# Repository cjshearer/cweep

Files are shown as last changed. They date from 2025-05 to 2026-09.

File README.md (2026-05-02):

## Overview

A compact, 34 key, solar powered, reversible, split keyboard.

<a href="https://github.com/user-attachments/assets/642829ea-e7b8-4ff3-9049-28f1e1555cb2">pcb-3d-bottom</a><a href="https://github.com/user-attachments/assets/ab504e79-e15f-4af2-8a4f-50c7394c724b">pcb-3d-top</a>

<a href="https://github.com/user-attachments/assets/e60e4d48-c13d-41c2-b896-f076ac4e2c79">pcb-B</a><a href="https://github.com/user-attachments/assets/00cfc082-f974-4577-bfa2-e2fe745e49d9">pcb-F</a>

<details>
  <summary>
    Schematic
  </summary>

  <a href="https://github.com/user-attachments/assets/647d1b9f-04d2-43af-ba33-3fea434be137">
    schematic
  </a>
</details>

## Case

The case is generated from `cweep.py` using CadQuery, with geometry extracted from user layers in `cweep.kicad_pcb`.

Generate case files to `case/`:

```sh
nix develop .#case --command python ~/repos/cweep/cweep.py
```

For interactive 3D viewing with live reloads:

```sh
nix develop .#case --command python ~/repos/cweep/cweep-dev.py
```

Changes to `cweep.py` or `cweep.kicad_pcb` automatically reload in the browser.

## Firmware

[*Generated by Shield Wizard for ZMK*](https://shield-wizard.genteure.workers.dev)

Reproducible builds with [Nix](https://nixos.org) thanks to [lilyinstarlight/zmk-nix](https://github.com/lilyinstarlight/zmk-nix):

```sh
# flash firmware with xiao dongle, resetting each board first
nix run .#flash reset reset reset dongle left right

# flash firmware with left as central, resetting each board first
nix run .#flash reset reset left_central right

# build all firmware and flash it yourself
nix build .#firmware
```

Builds in GitHub Actions coming soon.

## Bill of Materials (BOM)

| Description | Count | Value | Source |
|---|---|---|---|
| Controller | 2 | [Seeed Xiao nRF52840](https://files.seeedstudio.com/wiki/XIAO/Seeed-Studio-XIAO-Series-SOM-Datasheet.pdf) | [Octopart](https://octopart.com/102010448-seeed+studio-126049022) |
| Controller Sockets | 4 | [310-43-107-41-001000](https://datasheet.octopart.com/310-43-107-41-001000-Mill-Max-datasheet-180673429.pdf) | [Octopart](https://octopart.com/310-43-107-41-001000-mill-max-657030) |
| Controller Pins | 28 | [3320-0-00-15-00-00-03-0](https://datasheet.octopart.com/3320-0-00-15-00-00-03-0-Mill-Max-datasheet-180682269.pdf) | [Octopart](https://octopart.com/3320-0-00-15-00-00-03-0-mill-max-29613931) |
| Battery/Reset Pogo Pins | 4 | [0906-0-15-20-76-14-11-0](https://datasheet.octopart.com/0906-0-15-20-76-14-11-0-Mill-Max-datasheet-180665642.pdf) | [Octopart](https://octopart.com/0906-0-15-20-76-14-11-0-mill-max-259418) |
| Battery | 2 | [ICR10440](https://www.powerstream.com/p/ICR10440-300mAh.pdf) | [Amazon](https://www.amazon.com/dp/B08H4RC1Y5) |
| Battery Contacts | 4 | [Keystone 230-1](https://docs.rs-online.com/a10d/0900766b8106e5ee.pdf) | [Octopart](https://octopart.com/230-1-keystone-154879) |
| Power Switch | 2 | [KAN-15](https://hackaday.io/project/174738-kan-15-led-tactile-switch/log/183418-switches-switches-switches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,KAN%2D15,-Finally%2C%20I%20found) | [Amazon](https://us.amazon.com/dp/B0BHH2FBQ5) |
| Reset Button | 2 | [B3F-1020](https://omronfs.omron.com/en_US/ecb/products/pdf/en-b3f.pdf) (adafruit 367) | [Octopart](https://octopart.com/b3f-1020-omron-46944) |
| Kailh Choc V1 Keycaps | 34 | DDC Choc PBT Blanks | [Keebd](https://keebd.com/products/ddc-choc-pbt-blank-keycaps?variant=43210242785432) |
| Kailh Choc V1 Switches | 34 | [PG1350](https://cdn-shop.adafruit.com/product-files/5113/CHOC+keyswitch_Kailh-CPG135001D01_C400229.pdf) (e.g. [Sunset](https://cdn.shopify.com/s/files/1/0523/0847/6068/files/Choc_Sunset_datasheet.pdf))  | [Keebd](https://keebd.com/products/sunset-tactile-choc-switches?variant=41676091981976) |
| Kailh Choc Hotswap Sockets | 34 | [A5118](https://cdn-shop.adafruit.com/product-files/5118/5118-Choc-Socket.pdf) | [Octopart](https://octopart.com/5118-adafruit+industries-119967299) |
| Diodes | 34 | [1N4148W](https://datasheet.octopart.com/1N4148W-Diotec-datasheet-178941572.pdf) | [Octopart](https://octopart.com/1n4148w-diotec-42312312) |
| Solar Cell | 2 | [SM141K04LV](https://waf-e.dubudisk.com/anysolar.dubuplus.com/techsupport@anysolar.biz/O18Ae0B/DubuDisk/www/Gen3/SM141K04LV%20DATA%20SHEET%20202007.pdf) | [Octopart](https://octopart.com/sm141k04lv-anysolar-120091681) |
| Boost Converter | 2 | [BQ25504](https://www.ti.com/document-viewer/bq25504/datasheet) | [Octopart](https://octopart.com/bq25504rgtr-texas+instruments-20530455) |
| 4.7μF Capacitor (CHV1, CSTOR1) | 4 | [CL10A475KP8NNNC](https://datasheet.octopart.com/CL10A475KP8NNNC-Samsung-Electro-Mechanics-datasheet-11791968.pdf) | [Octopart](https://octopart.com/cl10a475kp8nnnc-samsung+electro-mechanics-9301844) |
| 10nF Capacitor (CREF1, CBYP1) | 4 | [C0603C103K5RACTU](https://octopart.com/c0603c103k5ractu-kemet-133094) | [Octopart](https://datasheet.octopart.com/C0603C103K5RACTU-Kemet-datasheet-11898999.pdf) |
| 22μH Inductor (LBST1) | 2 | [ASPI-4030S-220M-T](https://datasheet.octopart.com/ASPI-4030S-220M-T-Abracon-datasheet-27893147.pdf) | [Octopart](https://octopart.com/aspi-4030s-220m-t-abracon-29811505) |
| 4.42MΩ Resistor (ROV1) | 2 | [CRCW06034M42FKEA](https://datasheet.octopart.com/CRCW06034M42FKEA-Vishay-datasheet-175423584.pdf) | [Octopart](https://octopart.com/crcw06034m42fkea-vishay-39804278) |
| 5.49MΩ Resistor (ROV2) | 2 | [CRCW06035M49FKEA](https://datasheet.octopart.com/CRCW06035M49FKEA-Vishay-datasheet-175423584.pdf) | [Octopart](https://octopart.com/crcw06035m49fkea-vishay-39809097) |
| 3.83MΩ Resistor (RUV1, ROC2) | 4 | [CRCW06033M83FKEA](https://datasheet.octopart.com/CRCW06033M83FKEA-Vishay-datasheet-175423584.pdf) | [Octopart](https://octopart.com/crcw06033m83fkea-vishay-39857567) |
| 6.04MΩ Resistor (RUV2) | 2 | [CRCW06036M04FKEA](https://datasheet.octopart.com/CRCW06036M04FKEA-Vishay-datasheet-175423584.pdf) | [Octopart](https://octopart.com/crcw06036m04fkea-vishay-39816007) |
| 16MΩ Resistor (ROC1) | 2 | [RK73B1JTTDD166J](https://datasheet.octopart.com/RK73B1JTTDD166J-KOA-Speer-datasheet-182143539.pdf) | [Octopart](https://octopart.com/rk73b1jttdd166j-koa+speer-20075546) |
| 24AWG Stranded Silicone Wire | ~8in | N/A | [Amazon](https://www.amazon.com/dp/B01LH1G2IE) |

## Credits

This project is inspired by the work of many in the custom keyboard community:

- Pierre Chavalier's [Ferris](https://github.com/pierrechevalier83/ferris): for the original design and layout
- David Philip Barr's [Sweep](https://github.com/davidphilipbarr/Sweep/): inspiration to build a wireless, ferris-like keyboard using a daughter board for the microcontroller  
- GEIGEIGEIST's [TOTEM](https://github.com/GEIGEIGEIST/TOTEM): for it's excellent build guide, which helped me understand what types of components I may need for a wireless split keyboard
- Pete Johanson's [revxlp](https://gitlab.com/lpgalaxy/revxlp): for the usage and layout of pogo pins to connect a socketed Seeed Xiao's battery and reset pins to the PCB
- Xudongz's [Ergoblue](https://www.xudongz.com/blog/2020/ergoblue/): my initial inspiration for building a solar powered wireless keyboard
- NGuyen Vincent's [Aloidia](https://hackaday.io/project/189688-aloidia-wireless-split-solar-powered-keyboard): for the detailed build log and all-around excellent resource on building solar powered wireless keyboard

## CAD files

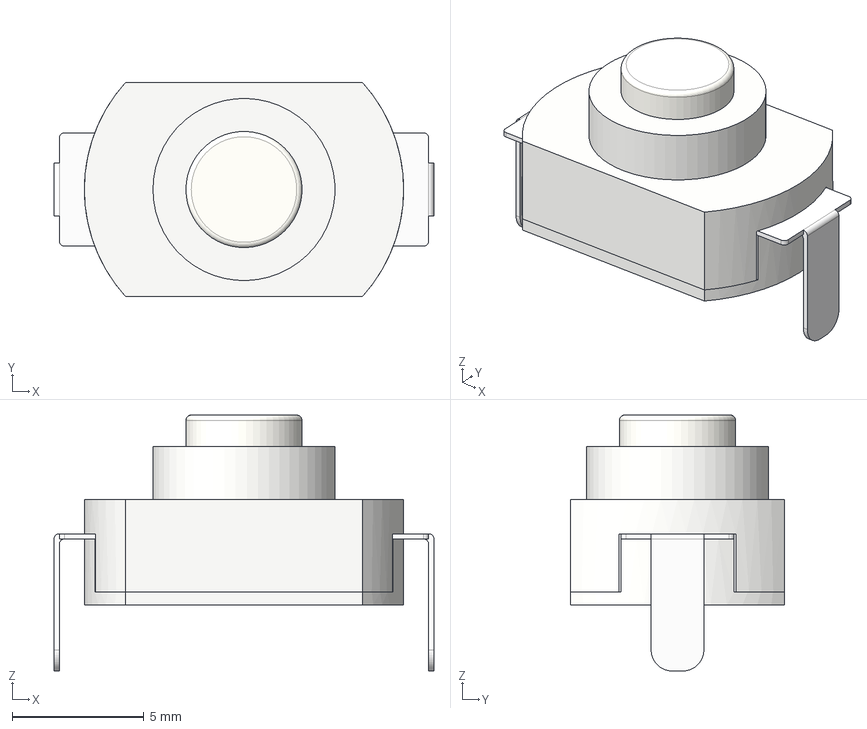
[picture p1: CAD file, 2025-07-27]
3dmodels/com_github_jgillick_KiCad-library/SW_KAN-15_PTH.step
14.4 x 8.10 x 9.70 mm

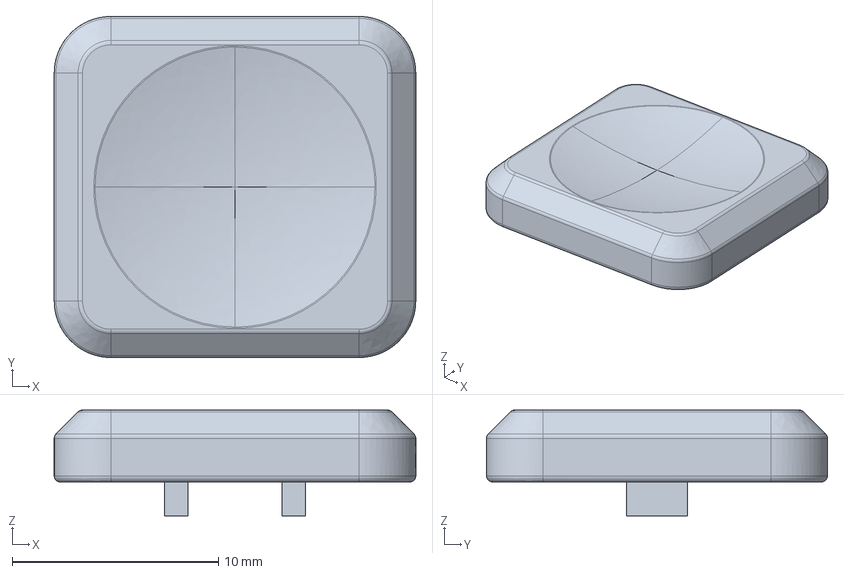
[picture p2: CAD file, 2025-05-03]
3dmodels/com_github_klouderone_KEA-choc-keycaps/KEA Choc V1 Choc Spaced Keycap 1u.stp
17.6 x 16.6 x 5.14 mm

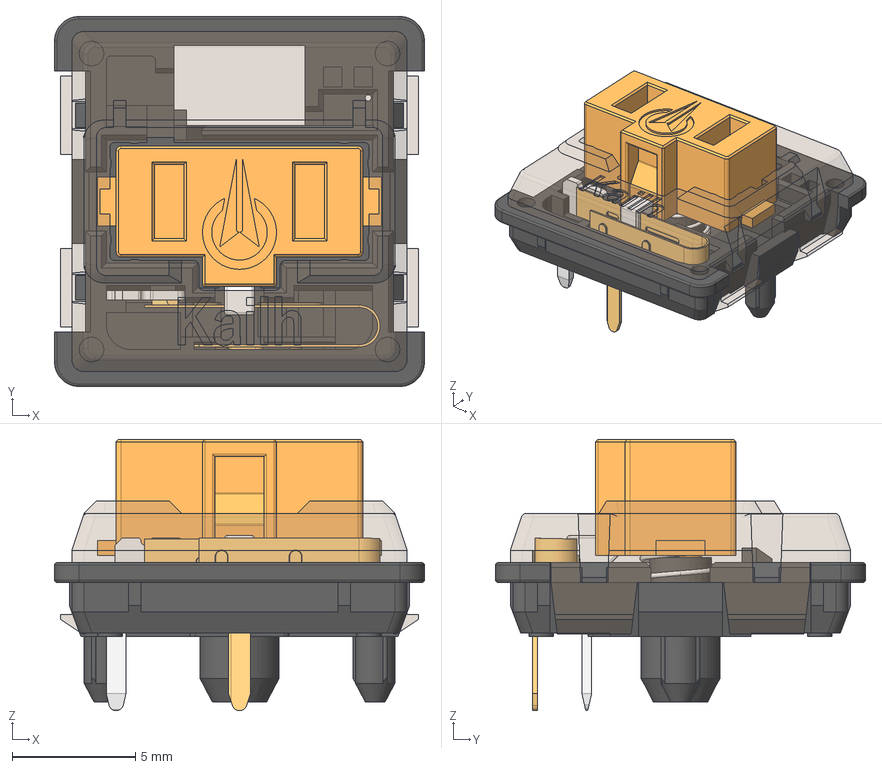
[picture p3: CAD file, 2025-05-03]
3dmodels/com_github_koktoh_keyswitch_model/sunset_tactile.step
15.0 x 15.0 x 11.0 mm
shrunken_spring
top
pin1
bottom
contact
stem_sunset_tactile
pin2

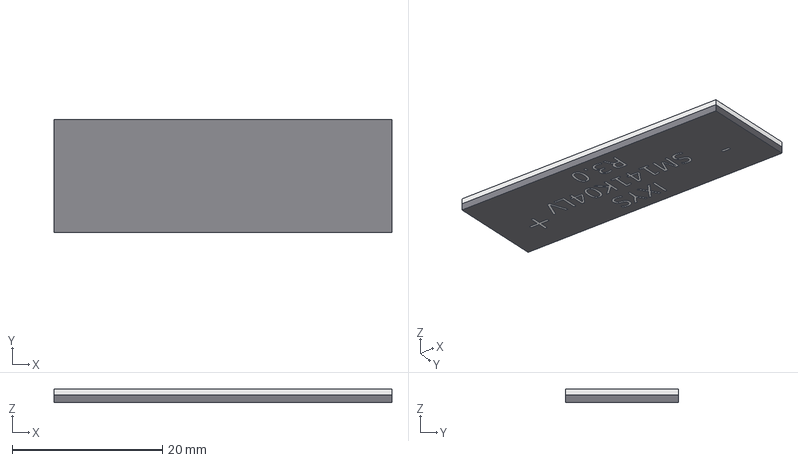
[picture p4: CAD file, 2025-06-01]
3dmodels/com_github_PeakSat_COMMSBoard_PCB/SM141K04LV.step
45.0 x 15.0 x 1.81 mm
+
SM141K04LV_substrate
SM141K04LV
SM141K04LV001
IXYS
R3.0

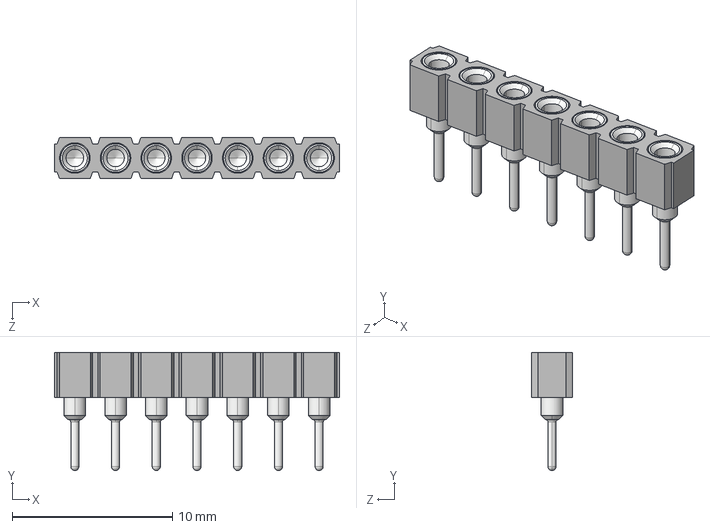
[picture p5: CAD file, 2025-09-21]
3dmodels/com_mouser_Mill-Max_310-43-107-41-001000/310-43-107-41-001000.stp
17.8 x 7.37 x 2.54 mm
P3XX-11-010-00-000000_P307-11-010-00-000000

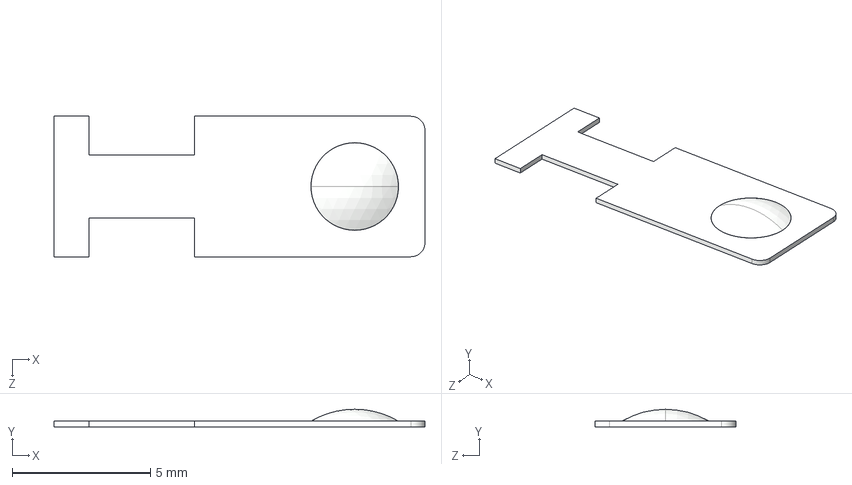
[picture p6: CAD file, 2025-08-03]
3dmodels/com_snapeda_Keystone/230-1.step
13.4 x 0.635 x 5.08 mm

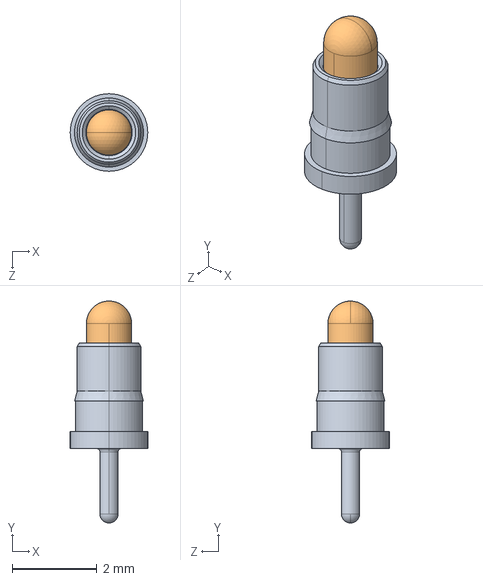
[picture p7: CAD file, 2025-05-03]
3dmodels/com_snapeda_Mill-Max_0906-0-15-20-76-14-11-0/0906-0-15-20-76-14-11-0.STEP
1.83 x 5.23 x 1.83 mm

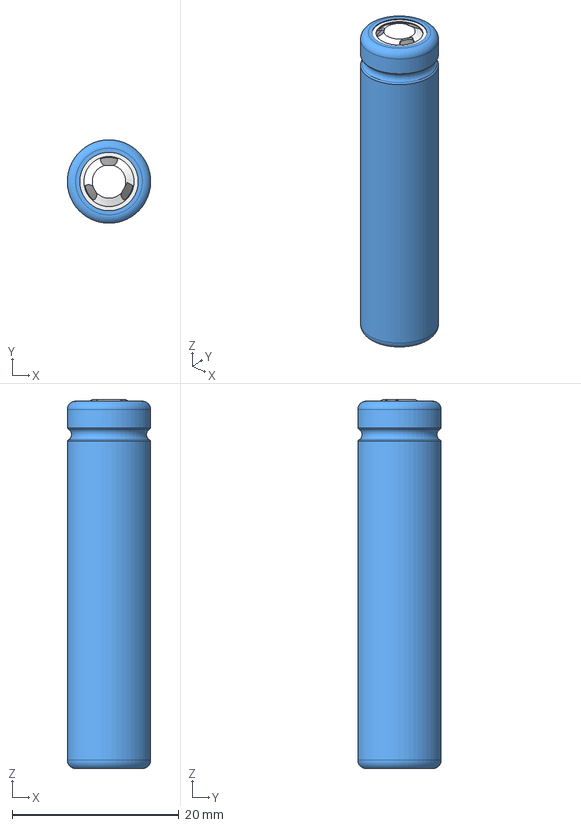
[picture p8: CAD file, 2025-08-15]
3dmodels/com_grabcad_ni_ni/10440.stp
10.00 x 9.99 x 44.2 mm

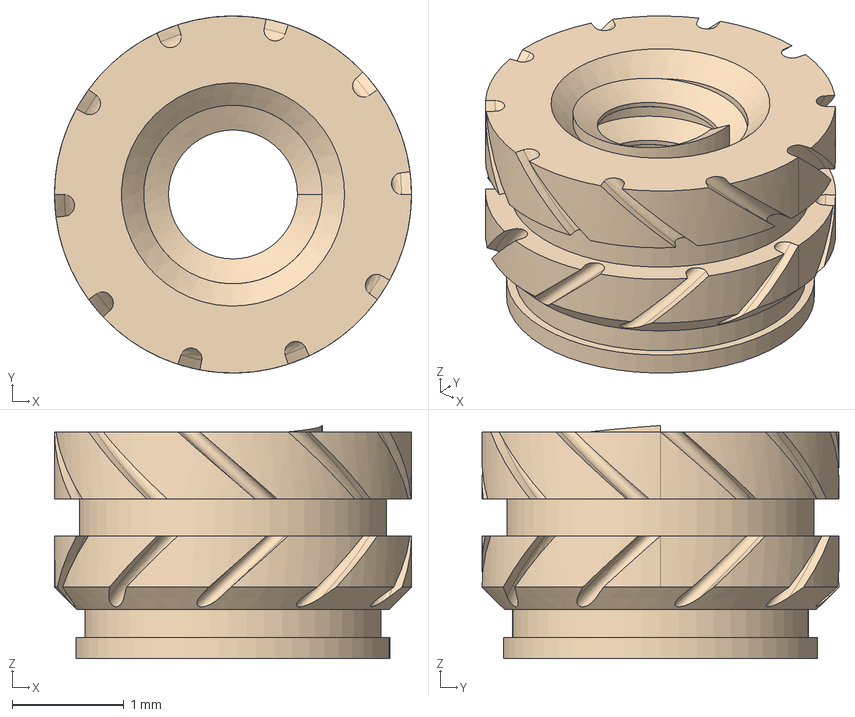
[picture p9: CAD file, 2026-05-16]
3dmodels/com_grabcad_shrey.g-2/m2x2x3.2_threaded-insert.step
3.20 x 3.20 x 2.09 mm

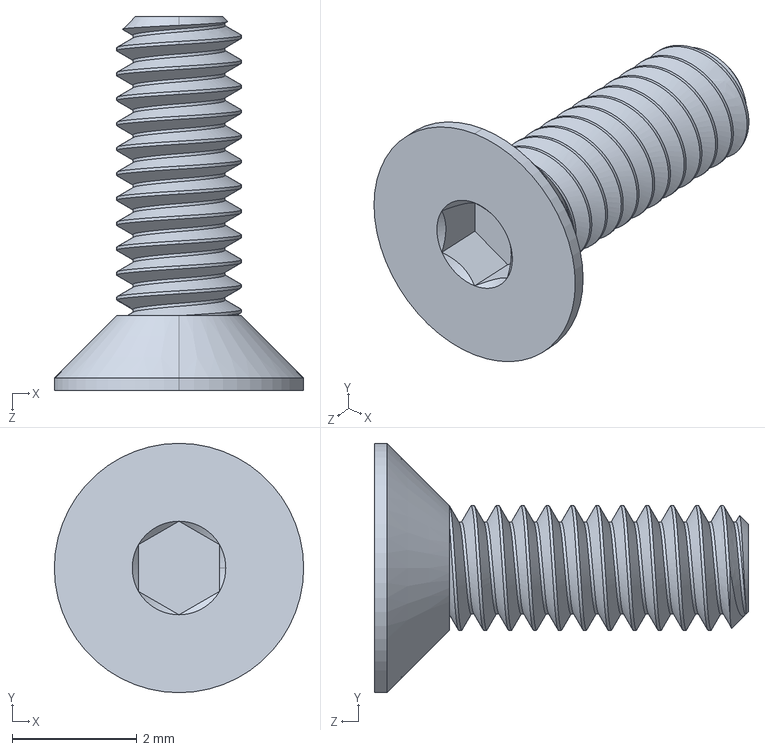
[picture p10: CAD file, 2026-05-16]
3dmodels/com_mcmaster/91294A004_hex_drive_flat_head_screw_m2x0.4x6.stp
4.00 x 4.00 x 6.00 mm

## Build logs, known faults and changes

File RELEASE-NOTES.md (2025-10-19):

## [0.2.1](https://github.com/cjshearer/cweep/compare/750787b...b826d47) (2025-10-19)

Features:

- feat: add firmware ([113380c](https://github.com/cjshearer/cweep/commit/113380c49dd21aa6a25552184e1d4649aa102922))
- feat: add direnv ([0741a76](https://github.com/cjshearer/cweep/commit/0741a76e008e20e344ac9841a19f397b33f8722a))
- feat: add cweep keymap ([b633da6](https://github.com/cjshearer/cweep/commit/b633da6e0e82b8d76da349570988fb77a3e8a74f))

Fixes:

- fix: add missing battery contacts ([88c9a56](https://github.com/cjshearer/cweep/commit/88c9a562178b62f404370517add00983ee9f83f7))
- fix: halves connect to dongle ([83709e9](https://github.com/cjshearer/cweep/commit/83709e9c3aa1ab0f535ac7c3a69aa6747a3f2635))
- fix: flip ground solder jumper pad ([0215cbb](https://github.com/cjshearer/cweep/commit/0215cbbeff3e0590acb6301ef7a46215b0a98009))
- fix: don't overlap jumper pad and rst courtyards ([0fad872](https://github.com/cjshearer/cweep/commit/0fad872a907a0e8da5768718c7a9fdc3f7a297eb))

Refactors:

- refactor: use low-leakage diodes ([2f691b7](https://github.com/cjshearer/cweep/commit/2f691b733773dad2b2d1976309e2343cbaab739a))
- refactor: dedup part for RUV1 and ROC2 ([7067be4](https://github.com/cjshearer/cweep/commit/7067be46746762ad8baf1e19320a376f6aba2be4))

Documentation:

- docs: update images ([5de7789](https://github.com/cjshearer/cweep/commit/5de77895a8b004a01328f5c3008dabf0e4f57216))
- docs: fix wrong image src ([6230c71](https://github.com/cjshearer/cweep/commit/6230c71ce97863de70a56a3e878f5c5da012389e))
- docs: shorten link for 24AWG wire ([95858cf](https://github.com/cjshearer/cweep/commit/95858cf211d6f48bfaf01f0d3ccf909587eeb3d1))

## [0.2.0](https://github.com/cjshearer/cweep/compare/6999a66...750787b) (2025-09-21)

Documentation:

- docs: update images ([49f538c](https://github.com/cjshearer/cweep/commit/49f538cf55e573baeba76378d8cd62a7de93a850))

Refactors:

- refactor: replace 311-13-107-41-001000 socket with cheaper alternative (310-43-107-41-001000) ([27b2981](https://github.com/cjshearer/cweep/commit/27b29816245fa6ae4417d3368c466a664c287341))

## [0.1.0](https://github.com/cjshearer/cweep/compare/d12c479...6999a66) (2025-09-21)

Fixes:

- fix: replace 310-87-107-41-001101 socket with normally stocked 311-13-107-41-001000 ([e322841](https://github.com/cjshearer/cweep/commit/e3228419793ac6dbd01cdbf91dbdef63a59cec45))

Documentation:

- docs: update KAN-15 with active source ([4c134dd](https://github.com/cjshearer/cweep/commit/4c134dd85159a258c3dca58db751e88ffd1d7f4d))

## [0.0.0](https://github.com/cjshearer/cweep/commit/d12c479) (2025-09-20)

init

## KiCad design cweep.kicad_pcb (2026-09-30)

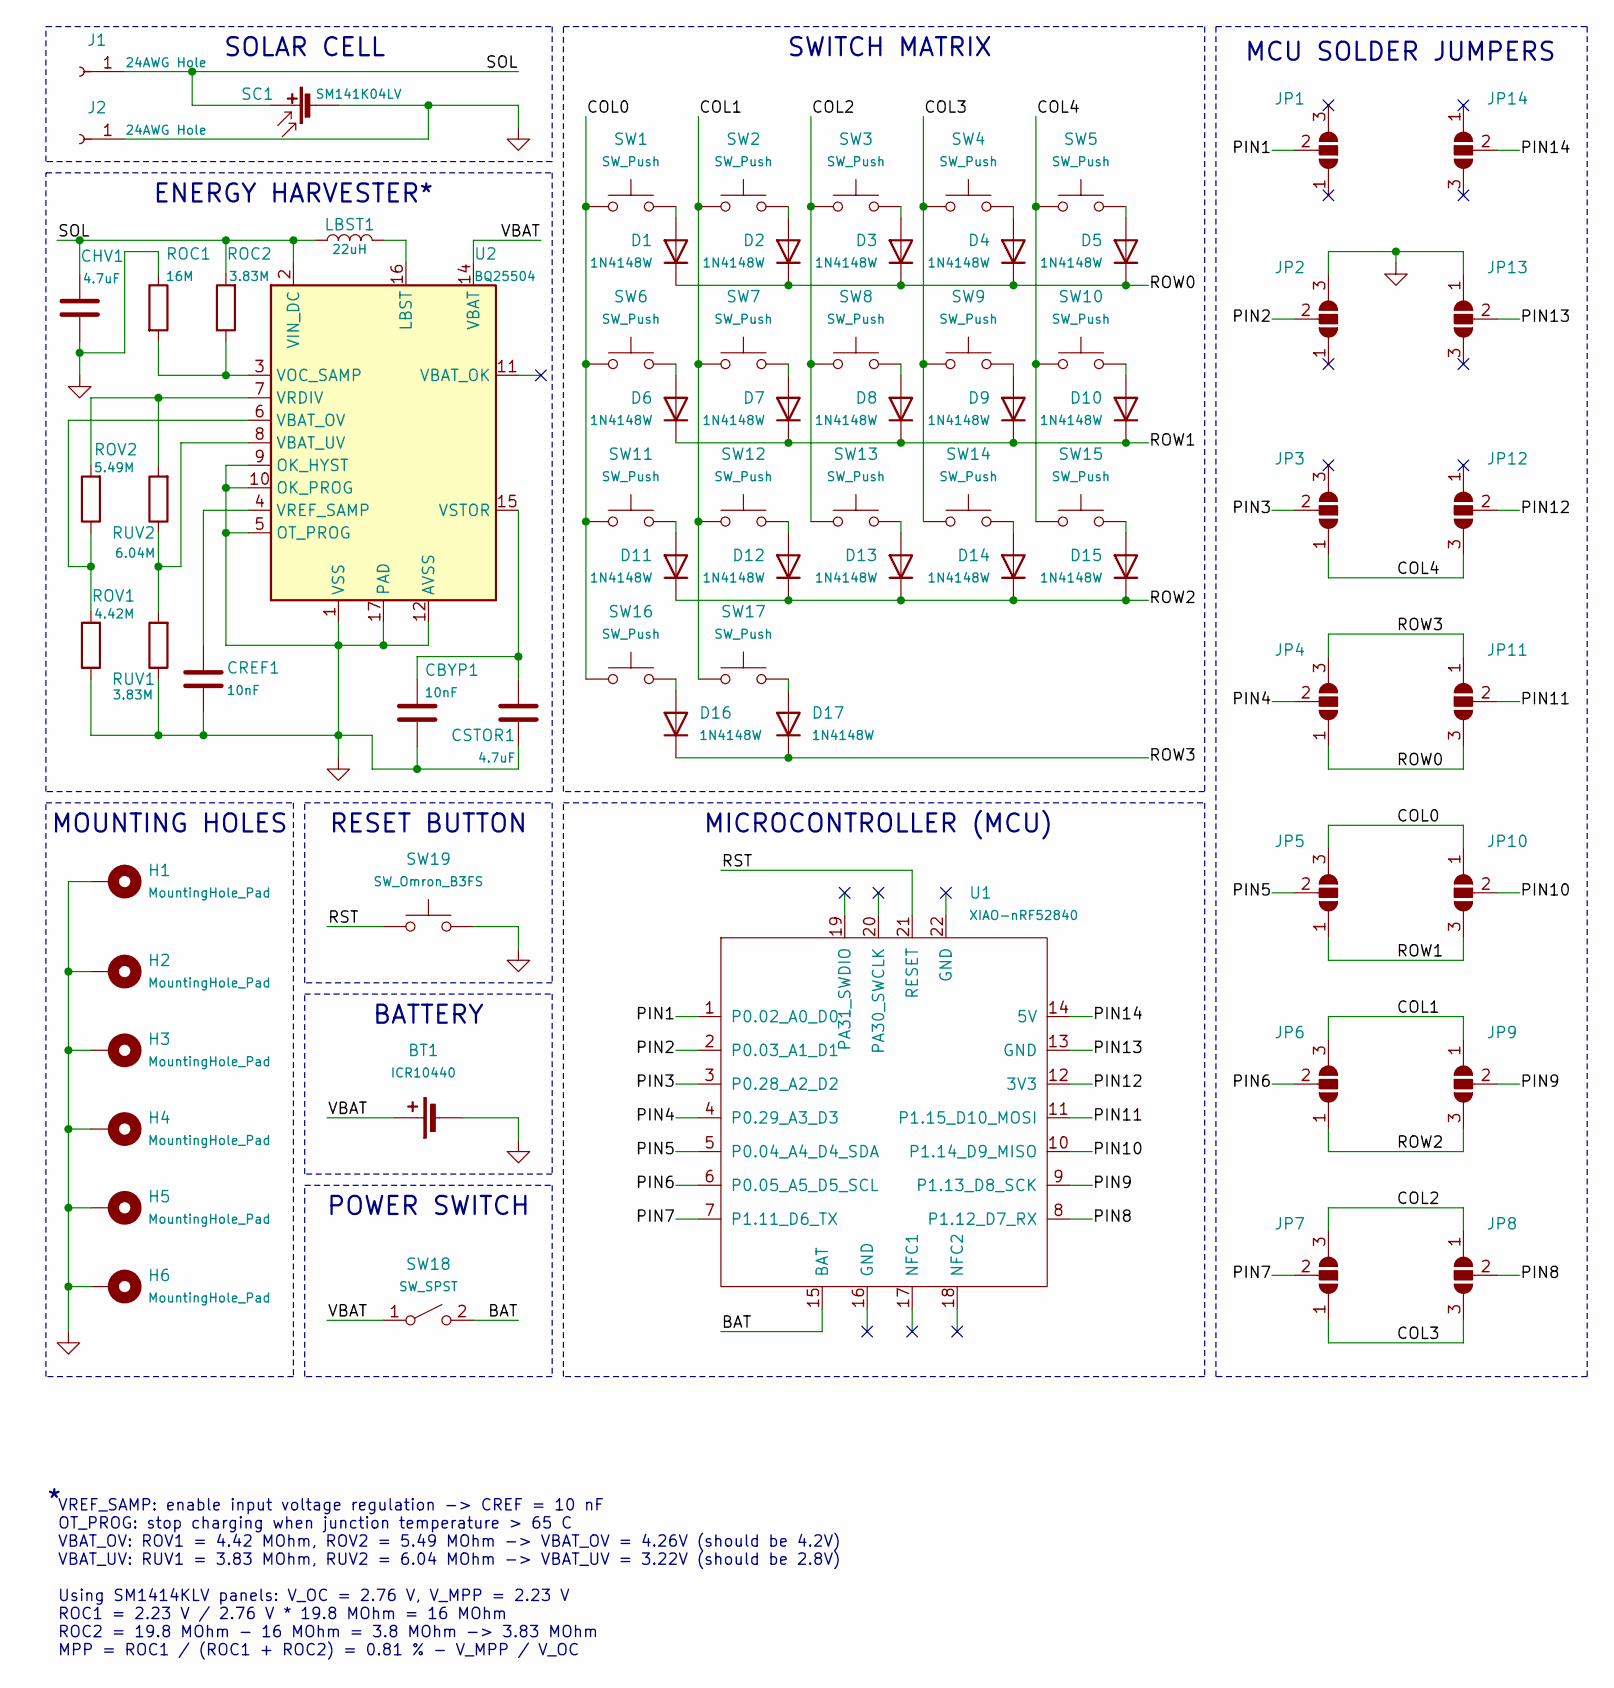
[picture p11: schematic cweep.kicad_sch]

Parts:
BT1: ICR10440; BatteryHolder_Keystone_230-1_1x10440
CBYP1: 10nF; C_0603_1608Metric_Pad1.08x0.95mm_HandSolder
CHV1: 4.7uF; C_0603_1608Metric_Pad1.08x0.95mm_HandSolder
CREF1: 10nF; C_0603_1608Metric_Pad1.08x0.95mm_HandSolder
CSTOR1: 4.7uF; C_0603_1608Metric_Pad1.08x0.95mm_HandSolder
D1, D2, D3, D4, D5, D6, D7, D8, D9, D10, D11, D12, D13, D14, D15, D16, D17: 1N4148W; D_SOD-123_Reversible
H1, H2, H3, H4, H5, H6: MountingHole_Pad; MountingHole_2.2mm_M2_DIN965_Pad
J1, J2: 24AWG Hole; SolderWire-0.127sqmm_1x01_D0.48mm_OD1mm_Relief
JP1, JP2, JP3, JP4, JP5, JP6, JP7, JP8, JP9, JP10, JP11, JP12, JP13, JP14: SolderJumper_3_Open; SolderJumper-3_P2.0mm_Open_TrianglePad1.0x1.5mm_Reversible
LBST1: 22uH; L_Abracon_ASPI-4030S_Reversible
ROC1: 16M; R_0603_1608Metric_Pad0.98x0.95mm_HandSolder
ROC2: 3.83M; R_0603_1608Metric_Pad0.98x0.95mm_HandSolder
ROV1: 4.42M; R_0603_1608Metric_Pad0.98x0.95mm_HandSolder
ROV2: 5.49M; R_0603_1608Metric_Pad0.98x0.95mm_HandSolder
RUV1: 3.83M; R_0603_1608Metric_Pad0.98x0.95mm_HandSolder
RUV2: 6.04M; R_0603_1608Metric_Pad0.98x0.95mm_HandSolder
SC1: SM141K04LV
SW1, SW2, SW3, SW4, SW5, SW6, SW7, SW8, SW9, SW10, SW11, SW12, SW13, SW14, SW15, SW16, SW17: SW_Push; SW_Hotswap_Kailh_Choc_V1_1.00u_Reversible
SW18: SW_SPST; SW_KAN-15_PHT_Reversible
SW19: SW_Omron_B3FS; SW_TH_Tactile_Omron_B3F-102x_Reversible
U1: XIAO-nRF52840; XIAO-nRF52840_Reversible
U2: BQ25504; VQFN-16-1EP_3x3mm_P0.5mm_EP1.68x1.68mm

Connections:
/BAT: SW18.2 (B), U1.15 (BAT)
/COL0: JP5.3 (B), JP10.1 (A), SW1.1, SW6.1, SW11.1, SW16.1
/COL1: JP6.3 (B), JP9.1 (A), SW2.1, SW7.1, SW12.1, SW17.1
/COL2: JP7.3 (B), JP8.1 (A), SW3.1, SW8.1, SW13.1
/COL3: JP7.1 (A), JP8.3 (B), SW4.1, SW9.1, SW14.1
/COL4: JP3.1 (A), JP12.3 (B), SW5.1, SW10.1, SW15.1
/PIN1: JP1.2 (C), U1.1 (P0.02_A0_D0)
/PIN2: JP2.2 (C), U1.2 (P0.03_A1_D1)
/PIN3: JP3.2 (C), U1.3 (P0.28_A2_D2)
/PIN4: JP4.2 (C), U1.4 (P0.29_A3_D3)
/PIN5: JP5.2 (C), U1.5 (P0.04_A4_D4_SDA)
/PIN6: JP6.2 (C), U1.6 (P0.05_A5_D5_SCL)
/PIN7: JP7.2 (C), U1.7 (P1.11_D6_TX)
/PIN8: JP8.2 (C), U1.8 (P1.12_D7_RX)
/PIN9: JP9.2 (C), U1.9 (P1.13_D8_SCK)
/PIN10: JP10.2 (C), U1.10 (P1.14_D9_MISO)
/PIN11: JP11.2 (C), U1.11 (P1.15_D10_MOSI)
/PIN12: JP12.2 (C), U1.12 (3V3)
/PIN13: JP13.2 (C), U1.13 (GND)
/PIN14: JP14.2 (C), U1.14 (5V)
/ROW0: D1.1 (K), D2.1 (K), D3.1 (K), D4.1 (K), D5.1 (K), JP4.1 (A), JP11.3 (B)
/ROW1: D6.1 (K), D7.1 (K), D8.1 (K), D9.1 (K), D10.1 (K), JP5.1 (A), JP10.3 (B)
/ROW2: D11.1 (K), D12.1 (K), D13.1 (K), D14.1 (K), D15.1 (K), JP6.1 (A), JP9.3 (B)
/ROW3: D16.1 (K), D17.1 (K), JP4.3 (B), JP11.1 (A)
/RST: SW19.1, U1.21 (RESET)
/SOL: CHV1.1, J1.1, LBST1.1, ROC2.2, SC1.1 (+), U2.2 (VIN_DC)
/VBAT: BT1.1 (+), SW18.1 (A), U2.14 (VBAT)
GND: BT1.2 (-), CBYP1.2, CHV1.2, CREF1.2, CSTOR1.2, H1.1, H2.1, H3.1, H4.1, H5.1, H6.1, J2.1, JP2.3 (B), JP13.1 (A), ROC1.1, ROV1.1, RUV1.1, SC1.2 (-), SW19.2, U2.1 (VSS), U2.5 (OT_PROG), U2.9 (OK_HYST), U2.10 (OK_PROG), U2.12 (AVSS), U2.13 (VSS), U2.17 (PAD)
unnamed: D1.2 (A), SW1.2
unnamed: D2.2 (A), SW2.2
unnamed: D3.2 (A), SW3.2
unnamed: D4.2 (A), SW4.2
unnamed: D5.2 (A), SW5.2
unnamed: D6.2 (A), SW6.2
unnamed: D7.2 (A), SW7.2
unnamed: D8.2 (A), SW8.2
unnamed: D9.2 (A), SW9.2
unnamed: D10.2 (A), SW10.2
unnamed: D11.2 (A), SW11.2
unnamed: D12.2 (A), SW12.2
unnamed: D13.2 (A), SW13.2
unnamed: D14.2 (A), SW14.2
unnamed: D15.2 (A), SW15.2
unnamed: D16.2 (A), SW16.2
unnamed: D17.2 (A), SW17.2
unnamed: LBST1.2, U2.16 (LBST)
unnamed: ROV1.2, ROV2.1, U2.6 (VBAT_OV)
unnamed: RUV1.2, RUV2.1, U2.8 (VBAT_UV)
unnamed: ROC1.2, ROC2.1, U2.3 (VOC_SAMP)
unnamed: ROV2.2, RUV2.2, U2.7 (VRDIV)
unnamed: CREF1.1, U2.4 (VREF_SAMP)
unnamed: CBYP1.1, CSTOR1.1, U2.15 (VSTOR)

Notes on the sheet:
MCU SOLDER JUMPERS
VREF_SAMP: enable input voltage regulation -> CREF = 10 nF OT_PROG: stop charging when junction temperature > 65 C VBAT_OV: ROV1 = 4.42 MOhm, ROV2 = 5.49 MOhm -> VBAT_OV = 4.26V (should be 4.2V) VBAT_UV: RUV1 = 3.83 MOhm, RUV2 = 6.04 MOhm -> VBAT_UV = 3.22V (should be 2.8V) Using SM1414KLV panels: 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
BATTERY
ENERGY HARVESTER*
SWITCH MATRIX
RESET BUTTON
MICROCONTROLLER (MCU)
POWER SWITCH
SOLAR CELL
MOUNTING HOLES

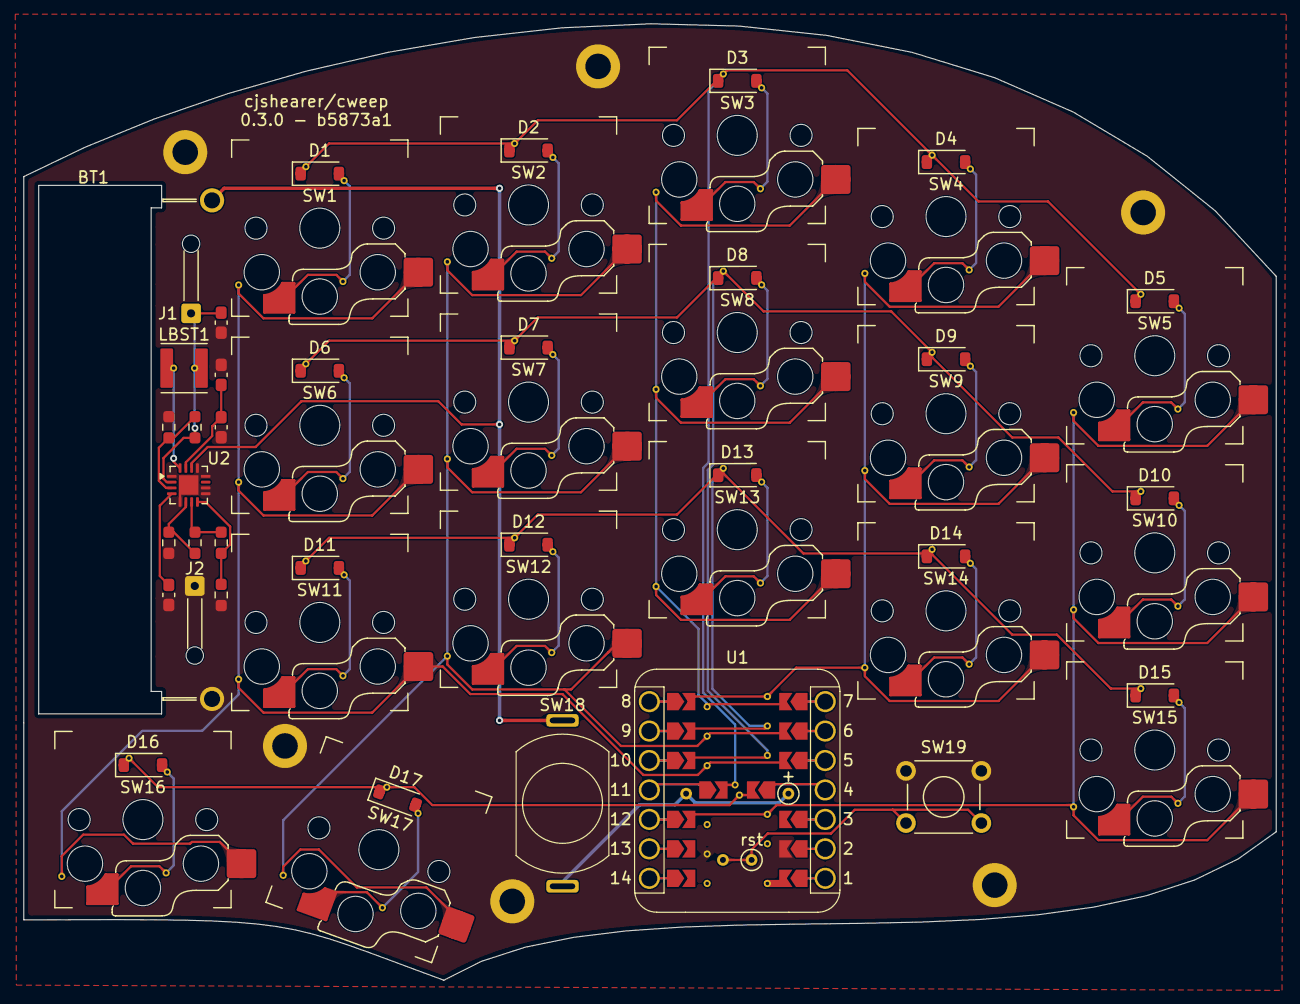
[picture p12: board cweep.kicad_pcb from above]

Board: 2 copper layers, 108.0 x 82.5 mm, 73 parts (1 on the bottom side), 52 nets.

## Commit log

2025-05-03 feat: add basic layout
    [cweep.kicad_pcb, cweep.kicad_sch]
2025-05-03 feat: add initial board layout
    [cweep.kicad_pcb]
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2025-05-03 feat: add matrix wiring
    [cweep.kicad_pcb, cweep.kicad_sch]
2025-05-03 refactor: flatten directory structure
    [KEA Choc V1 Choc Spaced Keycap 1u.stp, cweep.kicad_pcb, pcb_connector_310-87-107-41-001101.stp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]
2025-05-03 feat: add MCU battery pogo pin
    [0906-0-15-20-76-14-11-0.STEP, cweep.kicad_pcb, cweep.kicad_sch]
2025-05-03 feat: add MCU reset pogo pin
    [cweep.kicad_pcb]
2025-05-03 fix: mark unused pins
    [cweep.kicad_pcb, cweep.kicad_sch]
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2025-05-05 feat: add matrix-to-mcu routes
    [cweep.kicad_pcb, cweep.kicad_sch]
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2025-05-20 feat: add solar charging circuit
    [25mm-37mm-5mm-lipo-battery.step, RGT0016C.stp, cweep.kicad_pcb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]
2025-05-20 feat: add solar footprint and models
    [SM141K04LV.step, cweep.kicad_pcb, cweep.kicad_sch]
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2025-05-26 refactor: add R/L suffix
    [battery-13853-sparkfun-25x15x4.step, cweep.kicad_pcb, cweep.kicad_sch]
2025-05-26 feat: add matrix traces
    [cweep.kicad_pcb, cweep.kicad_sch]
2025-05-26 fix: placement for key-cap tolerances
    [cweep.kicad_pcb, cweep.kicad_sch]
2025-05-27 refactor: shorten column 0 trace
    [cweep.kicad_pcb, cweep.kicad_sch]
2025-05-28 docs: update bill-of-materials and todos
    [cweep.kicad_sch]
2025-05-31 refactor: remove unused no-connect
    [cweep.kicad_sch]
2025-05-31 fix: battery height
    [cweep.kicad_pcb]
2025-05-31 feat: add battery cutout
    [cweep.kicad_pcb]
2025-05-31 feat: add battery jst header
    [cweep.kicad_pcb, cweep.kicad_sch]
2025-05-31 fix: close hole in battery model
    [battery-13853-sparkfun-25x15x4.step]
2025-06-01 feat: add edge cuts
    [cweep.kicad_pcb]
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2025-06-01 refactor: fix solar cell appearance
    [SM141K04LV.step, cweep.kicad_pcb]
2025-06-07 feat: add mounting hole pads
    [cweep.kicad_pcb, cweep.kicad_sch]
2025-06-07 refactor: add plot settings
    [cweep.kicad_pcb]
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2025-06-21 feat: add solar harvester components
    [cweep.kicad_pcb, cweep.kicad_sch]
2025-06-21 fix: avoid text clipping
    [cweep.kicad_pcb]
2025-06-21 fix: add missing switch track
    [cweep.kicad_pcb]
2025-06-21 feat: add tracks for solar harvester
    [cweep.kicad_pcb]
2025-06-22 refactor: shorten row trace
    [cweep.kicad_pcb]
2025-07-26 refactor: typo in ultralibrarian
    [RGT0016C.stp, cweep.kicad_pcb, cweep.kicad_sch]
2025-07-27 feat: add reset button and power switch
    [SW_KAN-15_PTH.step, cweep.kicad_pcb, cweep.kicad_sch]
2025-08-01 fix: reorganize parts for better fit
    [cweep.kicad_pcb]
2025-08-02 fix: connect solar components to top pogo pin
    [cweep.kicad_pcb, cweep.kicad_sch]
2025-08-03 feat: battery capacity 110mAh -> 350mAh
    [230-1.step, AAA-Battery.STEP, battery-13853-sparkfun-25x15x4.step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]
2025-08-05 fix: remove unused pogo pins from solar cell
    [cweep.kicad_pcb]
2025-08-05 fix: battery connector spacing
    [cweep.kicad_pcb]
2025-08-06 fix: re-attach solar components
    [cweep.kicad_pcb]
2025-08-06 refactor: clean up solar fabrication labels
    [cweep.kicad_pcb]
2025-08-07 fix: align reset switch with power switch
    [cweep.kicad_pcb]
2025-08-08 fix: re-attach traces for gpio, power, and reset switches
    [cweep.kicad_pcb, cweep.kicad_sch]
2025-08-09 refactor: improve traces routing
    [cweep.kicad_pcb]
2025-08-09 fix: minor footprint and label alignments
    [cweep.kicad_pcb, cweep.kicad_sch]
2025-08-09 feat: add case mounting holes
    [cweep.kicad_pcb, cweep.kicad_sch]
2025-08-09 feat: 2.5mm -> 2.2mm mounting holes
    [cweep.kicad_pcb, cweep.kicad_sch]
2025-08-09 fix: visually align power and reset switches
    [cweep.kicad_pcb]
2025-08-09 fix: join solar ground zone and avoid silkscreen clipping
    [cweep.kicad_pcb, cweep.kicad_sch]
2025-08-10 fix: add missing B3F-102x model
    The model is broken and will be until
    https://gitlab.com/kicad/libraries/kicad-packages3D/-/merge_requests/1239
    lands.
    [cweep.kicad_pcb]
2025-08-10 refactor: add solar cell contact labels
    [cweep.kicad_pcb]
2025-08-10 refactor: center battery silkscreen label
    [cweep.kicad_pcb]
2025-08-10 fix: solar cell contact radius
    [cweep.kicad_pcb]
2025-08-10 refactor: reorganize battery schematic
    [cweep.kicad_sch]
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2025-08-15 fix: AAA -> 10440
    [10440.stp, AAA-Battery.STEP, cweep.kicad_pcb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]
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2025-09-09 feat: make keyboard switch reversible
    * fix: use SMD diode to accommodate reversible switch
    [cweep.kicad_pcb, cweep.kicad_sch]
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2025-09-09 fix: move capacitors nearer BQ25504
    The layout guidelines for the BQ25504 recommend
    placing the output capacitors as close as possible
    to the IC, followed by the input capacitors, and
    finally the inductor.
    Previously, I had this backwards, but with this
    commit the components are now in the recommended
    order.
    [cweep.kicad_pcb]
2025-09-09 fix: solar cell placement
    [cweep.kicad_pcb]
2025-09-09 fix: increase battery cutout
    I increased the size of the battery cutout to
    ensure the battery clips fit in the cutout. I left
    the battery clips where they were, since they are
    42.99mm apart, which is 1mm less than what the
    datasheet recommends for a AAA battery. However,
    the 10440 battery I will be using is 1mm smaller
    than a AAA, so this should be fine.
    [cweep.kicad_pcb]
2025-09-09 fix: xiao silkscreen
    The silkscreen for the reversible xiao footprint
    was confusing, so I updated it to be more clear.
    [cweep.kicad_pcb]
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2025-09-17 fix: correct footprint for inductor
    [cweep.kicad_pcb, cweep.kicad_sch]
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2025-09-19 fix: remove unused zone exclusion
    [cweep.kicad_pcb]
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2025-09-21 fix: replace socket with on normally in stock
    [311-13-107-41-001000.STEP, cweep.kicad_pcb, pcb_connector_310-87-107-41-001101.stp]
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2025-09-21 refactor: replace socket with cheaper alternative
    [310-43-107-41-001000.stp, 311-13-107-41-001000.STEP, cweep.kicad_pcb]
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2025-09-21 refactor: use low-leakage diodes
2025-09-25 fix: add missing battery contacts
2025-10-16 fix: flip ground solder jumper pad
    The MCU's GND solder jumper pad was incorrectly
    flipped in the PCB layout, requiring it to be
    bridged on the wrong side.
    This commit corrects the orientation of the solder
    jumper, so that it can be bridged on the correct
    side. Now, solder jumpers should all be bridged on
    the back of the PCB, regardless of which side of
    the keyboard the PCB is used for.
    [cweep.kicad_pcb]
2025-10-19 fix: don't overlap jumper pad and rst courtyards
    [cweep.kicad_pcb]
2025-10-19 docs: shorten link for 24AWG wire
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2025-10-19 feat: annotate hotswap kailh choc for case generation
    To generate the case for each side of the
    keyboard, I will be annotating the footprint and
    placement of each physical component with F.Right,
    B.Right, F.Left, or B.Left (User.1 through
    User.4).
    In this commit, I have annotated the hotswap kailh
    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
    [cweep.kicad_pcb]
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2025-10-20 fix: close gap in power switch F.Left annotation
    [cweep.kicad_pcb]
2025-10-22 fix: use accurate kailh choc CPG135001S30 socket
    There were no high quality footprints for the
    Kailh Choc hotswap sockets, so I created one based
    on the original line art from the datasheet to
    improve accuracy.
    [cweep.kicad_pcb]
2025-10-22 fix: power switch overlapping courtyard
    [cweep.kicad_pcb]
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2025-11-23 feat: add reset switch cutouts and model paths
    [cweep.kicad_pcb]
2025-11-23 refactor: swap wrl for stp
    STEP exports better for use in OpenScad.
    [cweep.kicad_pcb]
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2025-11-23 fix: remove small walls from switch cutouts
    [cweep.kicad_pcb]
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2025-11-27 fix: correct user layer assignments for front and back
    [cweep.kicad_pcb]
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2025-11-27 refactor: join right and left annotations
    Consolidate left/right cutout annotations into
    unified front/back layers. Prepare for future use
    of freed layers for fill regions.
    [cweep.kicad_pcb]
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2025-12-28 fix: cutout kailh hotswap contact
    [cweep.kicad_pcb]
2025-12-30 fix: close excess battery cutout for bottom plate
    [cweep.kicad_pcb]
2025-12-30 fix: kailh footprint is properly reversed
    [cweep.kicad_pcb]
2025-12-30 feat: add threaded M2 DIN 965 cutout to bottom plate
    [cweep.kicad_pcb]
2026-01-03 refactor: build plates from just bottom and top plate
    [cweep.kicad_pcb, cweep.scad]
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2026-02-17 refactor: replace some polygons with rectangles
    [cweep.kicad_pcb]
2026-02-22 fix: close cutout for omron switch
    [cweep.kicad_pcb]
2026-02-25 fix: close cutout for kailh choc sockets
    [cweep.kicad_pcb]
2026-03-01 fix: correct schematic footprint assignments
    [cweep.kicad_pcb, cweep.kicad_sch]
2026-03-01 fix: heal degenerate bezier in hotswap footprint
    The hotswap footprint had two cubic Bézier
    segments with coincident control points (Curve
    209: P0=P1, Curve 210: P2=P3), which creates
    zero-length endpoint tangents. That degenerate
    geometry causes OCCT/CadQuery offset2D to fail
    with "Null TopoDS_Shape" when generating User.5
    cutout offsets for the case. This change
    replaces/heals those degenerate segments so the
    outline remains functionally the same but is
    offset-safe and robust for automated case
    generation.
    [cweep.kicad_pcb]
2026-03-15 fix: widen power button cutout
    The power button's contacts would have collided
    with the case if not widened.
    [cweep.kicad_pcb]
2026-03-15 fix: remove small unnecessary cutout for omron
    [cweep.kicad_pcb]
2026-03-15 fix: simplify kailh switch cutout
    [cweep.kicad_pcb]
2026-03-18 fix: lower kailh switch model onto pcb
    [cweep.kicad_pcb]
2026-03-20 fix: align keycap model with switch
    [cweep.kicad_pcb]
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2026-04-25 fix: align xiao and its pads
    [cweep.kicad_pcb]
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2026-05-02 fix: enlarge solder wire top plate cutouts
    [cweep.kicad_pcb]
2026-05-02 fix: align battery cutouts
    [cweep.kicad_pcb]
2026-05-02 refactor: add empty SolarTop layer
    Insert a new empty User.1 "F.Plate.SolarTop" layer in the board layer
    table and shift the remaining User layers up by one, renaming them as
    they move:
    User.1 F.Plate.Solar -> User.2 F.Plate.SolarWall
    User.2 F.Plate.Cover -> User.3 F.Plate.Cover
    User.3 F.Plate.Switch -> User.4 F.Plate.Switch
    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
    [cweep.kicad_pcb]
2026-05-02 fix: raise battery model to match reality
    The battery doesn't sit perfectly in the notch cut for it, so we raise
    it up by 0.37mm, up from 6.53mm from top of pcb to top of battery to
    6.9mm.
    [cweep.kicad_pcb]
2026-05-02 refactor: replace openscad with cadquery
    [cweep.scad]
2026-05-09 feat: add solar battery compartment
    Add a compartment that houses the battery and provides a mounting point
    for the solar cell.
    The battery holder's plate cutouts are widened so the battery sits in a
    rounded recess, and the solar cell footprint is moved into its new
    position. New SolarTop/SolarWall plate outlines plus a few
    spacer/switch/cover items are drawn on the board, and the script now
    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
    [cweep.kicad_pcb]
2026-05-11 refactor: use shared tolerance
    Replace the separate CUT_TOLERANCE (0.127) and PRINT_TOLERANCE (0.2)
    constants with a single TOLERANCE = 0.2 used for every offset2D call,
    so the plate clearances stay consistent and easier to tune.
2026-05-15 refactor: skip PCB model generation if unchanged
    cweep-dev.py only re-exports the PCB assembly STEP when it is missing
    or older than the PCB file, avoiding a slow kicad-cli run on every
    reload of the viewer.
2026-05-16 feat: visualize screws and threaded inserts
    Import 3D models of the M2 flat-head screw and the heat-set threaded
    insert, and instance them at every mounting hole in the --preview
    viewer so the hardware fitment can be checked at a glance. The models
    live in 3dmodels/.
    [91294A004_hex_drive_flat_head_screw_m2x0.4x6.stp, m2x2x3.2_threaded-insert.step]
2026-05-23 refactor: extract geometry per footprint feature
    Replace the monolithic "all User layer wires" extraction with one that
    categorizes geometry by footprint feature. FEATURE_NAME_BY_LIB_ID maps
    each footprint lib ID to a feature name (solar_cell, mounting_holes,
    kailh_switches, battery_holder, ...), and board graphics are collected
    under "board_features". Pads are extracted onto a synthetic "drill"
    layer, which the mounting holes now use instead of the User.8 circles.
    Cut and fill recipes become data: BOTTOM_CUTOUT_FEATURES,
    TOP_CUT_OPERATIONS and TOP_FILL_OPERATIONS are lists of
    {thickness, features} dictionaries that drive the plate construction,
    paving the way for the stage-based pipeline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
2026-05-25 refactor: simplify per-feature cutout builders
    Rewrite the per-feature cutout builders as single fluent
    workplane -> sketch -> faces().wires().offset(TOLERANCE) -> extrude/cut
    chains, dropping the shared wire and solid helper functions. Extract
    pads (circle and roundrect) so the reset button and power switch
    bottoms can use real pad geometry, and dispatch the cutout construction
    via globals().get(f"build_{feature}_cutout").
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2026-05-26 refactor: cut per stage instead of per span
    The span-based pipeline was slow and its combined profiles hard to
    debug, so replace it with a per-stage loop: placements are grouped by
    angle and each feature stage is cut with one combined placed sketch.
    Restore the battery holder, kailh switches (bottom reconstructed from
    F.Fab/B.Fab/drill), inductors, capacitors, resistors, power IC, reset
    button, solder wires and power switch stages. A
    CWEEP_RESTORE_BATCH_COUNT env var (with RESTORED_FEATURE_BATCHES)
    allows the restored features to be re-enabled incrementally.
2026-05-26 fix: recalculate zone fill
    The zone fill was too close to a pad teardrop, causing a DRC error.
    Recalculate the fill, adjust the affected zone outlines, and drop nine
    redundant keyboard-matrix zones (ROW2/ROW0/ROW1/COL0/COL1 on F.Cu,
    ROW2/ROW1 on B.Cu) left over from an earlier experiment.
    [cweep.kicad_pcb]
2026-06-03 refactor: drive construction from feature_stages
    Move all construction into a feature_stages dictionary: each feature
    carries its placements and a set of named stages, each stage a sketch
    plus operations ({target, kind: union|cut, start, end, offset, apply})
    applied against the plate solids via a tagged base workplane. The
    plate shells and the solar component are expressed as features too,
    replacing the build_top_solar_component function.
    The mounting hole depth is now based on SCREW_LENGTH (6) instead of a
    fixed cut, and kailh switch cuts use a per-switch batch mode.
2026-06-07 fix: align surface normals of extracted geometry
    After the KiCad Y-axis flip, the assembled sketch faces ended up wound
    backwards. Traverse the directional primitives in reverse (segments
    end->start, reversed bezier/polygon coordinates, arcs end->mid->start)
    so the faces keep their normals pointing up.
2026-06-07 refactor: derive battery cutout from PCB geometry
    Replace the hand-authored battery top sketch with the battery holder
    footprint's Edge.Cuts geometry and the face of its F.CrtYd, renaming
    the feature to battery_cutout along the way.
2026-06-10 refactor: place features with cq.Location objects
    Replace the manual Y-negation and winding-reversal hacks with a single
    sketch.moved(cq.Location(rx=180)) applied to each assembled layer
    sketch, and switch footprint_placements from (angle, offset) tuples to
    cq.Location(offset=(x, -y, 0), rz=angle) objects placed via
    push(...).face(...).
    The solar component is rebuilt as a single main_body stage: the F.Fab
    outline offset by SOLAR_WALL_THICKNESS (3.9 -> 1.112), extruded from
    the top shell to the cell ceiling and filleted, with the battery
    compartment and cell cut out of it.
    The microcontroller and mounting hole features are temporarily disabled
    and exports commented out while the kailh upper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
2026-07-01 refactor: switch to direct feature creation
    The feature_stages dictionary grew harder to maintain than the
    construction it described, so the generic pipeline is replaced with
    direct, top-down feature blocks: each feature is a short sequence of
    workplaneFromTagged("base") + placeSketch + extrude/cutBlind calls
    grouped by commented section headers.
    This adds offset_profile, which moves each face to the origin before
    offsetting its wires, working around an OCC kernel bug that doubles the
    centre point when offsetting a circle wire that carries a non-identity
    TopLoc_Location (CadQuery issues #896, #2046). Extracted sketches are
    mirrored with rx=180 and their faces reversed so normals point up.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
2026-07-01 feat: add solar housing
    Add the solar housing: a box around the solar cell with a filleted
    top, a front battery opening with a wire chase that bridges from the
    battery cutout to the cell ceiling, a cell pocket cut to the cell
    depth, and clearance for the battery tabs that rise above the top
    shell.
    The power switch is moved out of the way (+3.25, +2.25) and swapped
    for the B3FS variant, and its track is rerouted; the schematic
    footprint references move to the cweep library. The SM141K04LV 3D
    model offset is raised so the cell sits inside the housing, the battery
    holder courtyard is simplified, and the XIAO F.Fab/B.Fab outline is
    redrawn with rounded corners. The zone fills are recalculated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
    [cweep.kicad_pcb, cweep.kicad_sch]
2026-08-08 fix: convert OffsetCurve edges to B-splines for STEP export
    Wire.offset2D can produce edges whose underlying geometry is an
    OffsetCurve (OCC curve type 7). Although the STEP specification defines
    offset_curve_3d for this type, the OCC STEP writer silently drops any
    face whose boundary contains such an edge. Three offset operations in
    offset_profile trigger this: the board outline offset (+2 mm and +0.2
    mm) and the kailh switch bottom pad offset (+0.2 mm).
    The fix adds _fix_offset_edges, called after each offset2D inside
    offset_profile. It detects OffsetCurve edges and replaces them with
    B-spline approximations via GeomAPI_PointsToBSpline -- the canonical
    curve-to-BSpline converter docume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
2026-08-08 chore: remove unused User.7 and User.8 layers
    The plate outline (User.7) and mounting hole circles (User.8) are no
    longer consumed by the case generation script -- the board outline
    comes from Edge.Cuts and the holes from the mounting hole footprint
    drills -- so drop the layer table entries, the board graphic items,
    and the fp_circle in the MountingHole footprint library.
    [cweep.kicad_pcb]
2026-08-08 chore: remove unused User.1 and User.2 layers
    The solar top/wall outlines (User.1/User.2) are no longer read by the
    script, so drop the layer table entries and the SolarTop/SolarWall
    graphic items added for the battery compartment.
    [cweep.kicad_pcb]
2026-08-08 refactor: replace usage of User layers with Fab
    The power switch's plate geometry is duplicated between the User.#
    layers and the footprint's own F.Fab outline. Point the case script
    at the switch's F.Fab outline instead of the procedural arc+rect
    sketch, and remove the User.3/4/5/6 items from the footprint so the
    plate geometry has a single source of truth.
    Regenerated item UUIDs from this edit are reverted in the library
    footprint.
    [cweep.kicad_pcb]
2026-08-08 fix: close power switch's F.Fab shape
    The F.Fab outline of the power switch was left open by a 1-micron gap;
    close it so the extracted profile assembles into a valid face. The
    footprint library and the board copy are both updated.
    [cweep.kicad_pcb]
2026-08-21 fix: tighten switch cutouts
    The switch cutouts have been made a little tighter
    so that, if you pull on a key cap, the key cap
    comes off before the switch comes out of the top
    plate.
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2026-08-21 fix: tighten switch cutouts
    The previous tightening of these switch cutouts
    helped, but the switch cutouts could still be just
    a tad tighter.
    If I pull on a key cap, the switch comes out
    before the key cap for about half of those tested.
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2026-09-28 fix: center battery access cutout on holder body
    The bottom access hole's center was hardcoded. Derive it from the
    midpoint of the battery holder body's long Edge.Cuts edges, ignoring
    the two tabs, and reuse _battery_top_sketch_placed in place of the
    tagged battery_top_sketch workplane.
2026-09-28 fix: convert offset curves to NURBS exactly
    Approximating each OffsetCurve edge with GeomAPI_PointsToBSpline can
    leave gaps between the rebuilt edges and produce self-intersecting
    faces at larger offsets, and Wire.Edges is not returned in traversal
    order. Convert the edges exactly with BRepBuilderAPI_NurbsConvert and
    reassemble them with Wire.assembleEdges.
2026-09-30 fix: increase backplate cut tolerance for powder coating
    The backplate is powder coated, so add 0.12mm on top of the 0.2mm
    cutting tolerance for every feature cut in it. This replaces the 2x
    tolerance that the 0603 and power IC clearances used.
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2026-09-30 fix: center solar cell and pocket on housing
    The pocket was cut at the solar cell footprint's PCB position, which sits ~0.53mm off the housing center derived from the top plate outline. Cut the pocket on _solar_center and move the footprint to the same point so the cell renders centered in the housing.
    [cweep.kicad_pcb]
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2026-10-02 fix: set backplate thickness and tolerances for SendCutSend
    Switch the backplate to SendCutSend's 1.88mm A1008 mild steel and size
    its cutouts for their fiber laser and powder coat: 0.127mm cut tolerance
    plus 0.127mm coating per side gives 0.254mm clearance, and the minimum
    web drops from 1mm to their 0.813mm minimum bridge.
2026-10-02 feat: lap the backplate into the skirt wall
    Offset the backplate outward by half the skirt thickness instead of
    matching the shell outline, and clear the lower skirt to that recess so
    the backplate laps into the wall (grown less by the cut tolerance so it
    fits). This keeps a 1mm wall around the backplate and retains the
    section between the bottom edge switches without widening the plate to
    the full shell outline.
2026-10-02 fix: cut out battery tabs from backplate
